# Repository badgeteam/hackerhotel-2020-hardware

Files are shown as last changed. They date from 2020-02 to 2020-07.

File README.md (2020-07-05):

# Hackerhotel 2020 badge
We hope you enjoyed the event!

# Using the design
Should you want to use this design for your own badges then keep in mind that the LED footprints are reversed. Because of this the current design is only suitable for manual assembly! Should you find time to create a version with the LED footprints the right way round (or with the transistors moved to the other side of the LEDs...) then please let us know by creating a pull request.

# License
CERN-OHL-P

Please send in an issue to this repository if you want to use this work under a different license.

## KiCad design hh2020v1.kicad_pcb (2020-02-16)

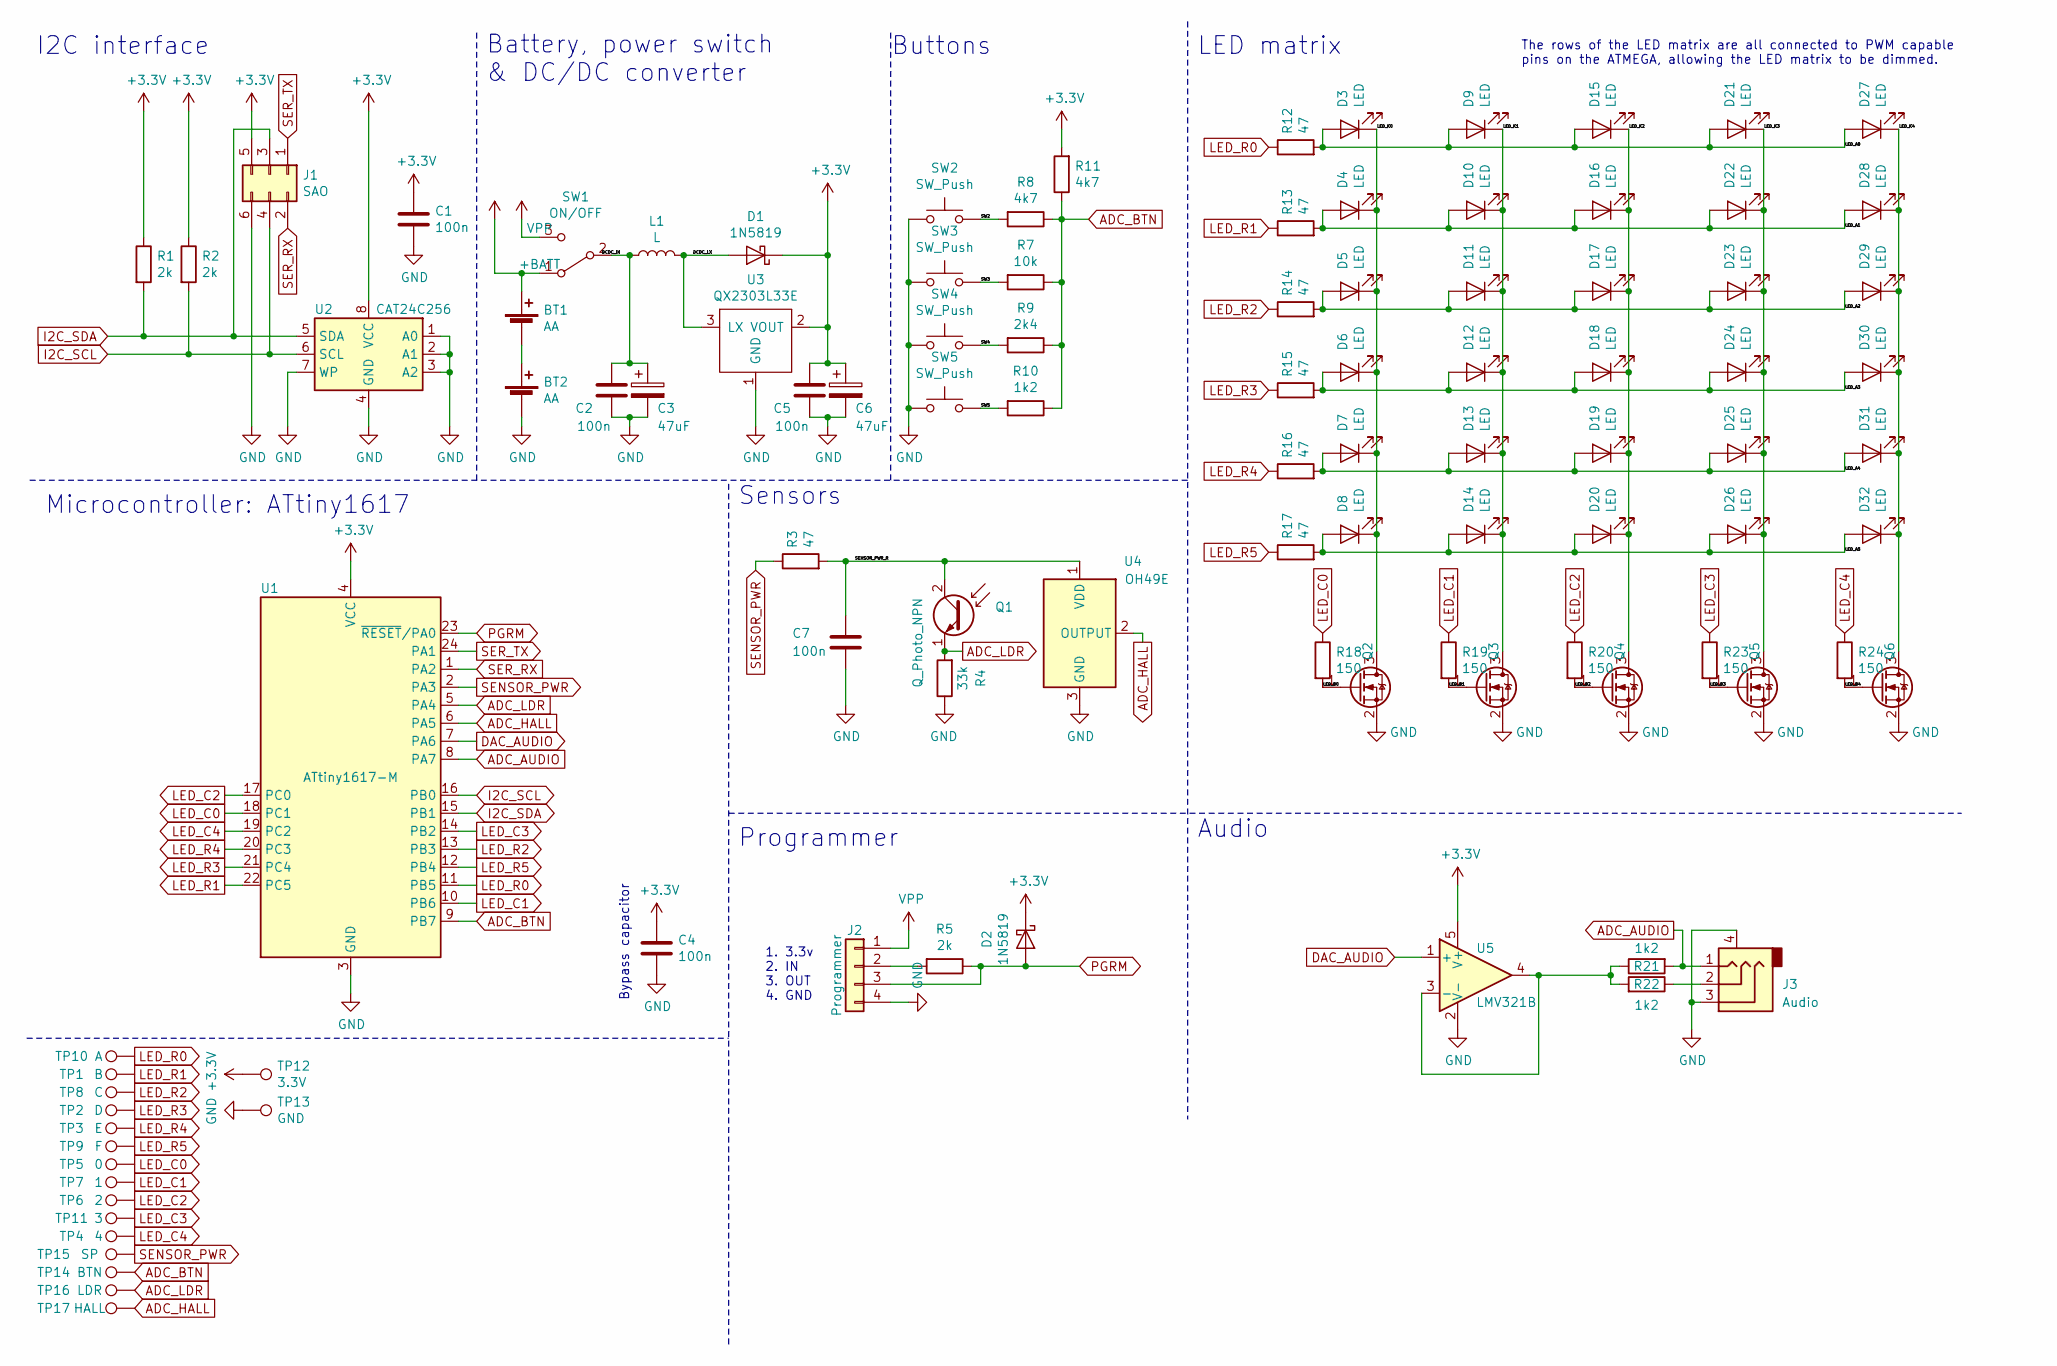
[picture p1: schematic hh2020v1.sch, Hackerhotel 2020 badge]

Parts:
BT1, BT2: AA; BatteryHolder_Keystone_2460_1xAA
C1, C2, C4, C5, C7: 100n; C_0603
C3, C6: 47uF; CP_Tantalum_Case-A_EIA-3216-18_Reflow
D1, D2: 1N5819; D_SOD-123
D3, D4, D5, D6, D7, D8, D9, D10, D11, D12, D13, D14, D15, D16, D17, D18, D19, D20, D21, D22, D23, D24, D25, D26, D27, D28, D29, D30, D31, D32: LED; led-sideways-2.0x0.5
J1: SAO; Pin_Header_Straight_2x03_Pitch2.54mm
J2: Programmer; Pin_Header_Straight_1x04_Pitch2.54mm
J3: Audio; PJ320D_3.5mm_Jack
L1: L; L_Bourns-SRN8040_8x8.15mm
Q1: Q_Photo_NPN; R_0805
Q2, Q3, Q4, Q5, Q6: Q_NMOS_GSD; SOT-23
R1, R2, R5: 2k; R_0603
R3, R12, R13, R14, R15, R16, R17: 47; R_0603
R4: 33k; R_0603
R7: 10k; R_0603
R8, R11: 4k7; R_0603
R9: 2k4; R_0603
R10, R21, R22: 1k2; R_0603
R18, R19, R20, R23, R24: 150; R_0603
SW1: ON/OFF; SW_SPDT_PCM12
SW2, SW3, SW4, SW5: SW_Push; SW_SPST_SKQG
TP1: B; TestPoint_Pad_1.0x1.0mm
TP2: D; TestPoint_Pad_1.0x1.0mm
TP3: E; TestPoint_Pad_1.0x1.0mm
TP4: 4; TestPoint_Pad_1.0x1.0mm
TP5: 0; TestPoint_Pad_1.0x1.0mm
TP6: 2; TestPoint_Pad_1.0x1.0mm
TP7: 1; TestPoint_Pad_1.0x1.0mm
TP8: C; TestPoint_Pad_1.0x1.0mm
TP9: F; TestPoint_Pad_1.0x1.0mm
TP10: A; TestPoint_Pad_1.0x1.0mm
TP11: 3; TestPoint_Pad_1.0x1.0mm
TP12: 3.3V; TestPoint_Pad_1.0x1.0mm
TP13: GND; TestPoint_Pad_1.0x1.0mm
TP14: BTN; TestPoint_Pad_1.0x1.0mm
TP15: SP; TestPoint_Pad_1.0x1.0mm
TP16: LDR; TestPoint_Pad_1.0x1.0mm
TP17: HALL; TestPoint_Pad_1.0x1.0mm
U1: ATtiny1617-M; QFN-24-1EP_4x4mm_P0.5mm_EP2.6x2.6mm
U2: CAT24C256; SOIC-8-N
U3: QX2303L33E; SOT-89-3
U4: OH49E; SOT-23
U5: LMV321B; SOT-23-5

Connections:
+3V3: C1.1, C4.1, C5.2, C6.1, D1.1 (K), D2.1 (K), J1.5, R1.1, R2.1, R11.2, TP12.1, U1.4 (VCC), U2.8 (VCC), U3.2 (VOUT), U5.5 (V+)
+BATT: BT1.1 (+), SW1.1 (A)
/DCDC_IN: C2.2, C3.1, L1.1, SW1.2 (B)
/DCDC_LX: D1.2 (A), L1.2, U3.3 (LX)
/LED_A0: D3.2 (A), D9.2 (A), D15.2 (A), D21.2 (A), D27.2 (A), R12.2
/LED_A1: D4.2 (A), D10.2 (A), D16.2 (A), D22.2 (A), D28.2 (A), R13.2
/LED_A2: D5.2 (A), D11.2 (A), D17.2 (A), D23.2 (A), D29.2 (A), R14.2
/LED_A3: D6.2 (A), D12.2 (A), D18.2 (A), D24.2 (A), D30.2 (A), R15.2
/LED_A4: D7.2 (A), D13.2 (A), D19.2 (A), D25.2 (A), D31.2 (A), R16.2
/LED_A5: D8.2 (A), D14.2 (A), D20.2 (A), D26.2 (A), D32.2 (A), R17.2
/LED_B0: Q2.1 (G), R18.2
/LED_B1: Q3.1 (G), R19.2
/LED_B2: Q4.1 (G), R20.2
/LED_B3: Q5.1 (G), R23.2
/LED_B4: Q6.1 (G), R24.2
/LED_K0: D3.1 (K), D4.1 (K), D5.1 (K), D6.1 (K), D7.1 (K), D8.1 (K), Q2.3 (D)
/LED_K1: D9.1 (K), D10.1 (K), D11.1 (K), D12.1 (K), D13.1 (K), D14.1 (K), Q3.3 (D)
/LED_K2: D15.1 (K), D16.1 (K), D17.1 (K), D18.1 (K), D19.1 (K), D20.1 (K), Q4.3 (D)
/LED_K3: D21.1 (K), D22.1 (K), D23.1 (K), D24.1 (K), D25.1 (K), D26.1 (K), Q5.3 (D)
/LED_K4: D27.1 (K), D28.1 (K), D29.1 (K), D30.1 (K), D31.1 (K), D32.1 (K), Q6.3 (D)
/SENSOR_PWR_R: C7.1, Q1.2 (E), R3.2, U4.1 (VDD)
/SW2: R8.2, SW2.2
/SW3: R7.2, SW3.2
/SW4: R9.2, SW4.2
/SW5: R10.2, SW5.2
ADC_AUDIO: J3.1, R21.2, U1.8 (PA7)
ADC_BTN: R7.1, R8.1, R9.1, R10.1, R11.1, TP14.1, U1.9 (PB7)
ADC_HALL: TP17.1, U1.6 (PA5), U4.2 (OUTPUT)
ADC_LDR: Q1.1 (C), R4.2, TP16.1, U1.5 (PA4)
DAC_AUDIO: U1.7 (PA6), U5.1 (+)
GND: BT2.2 (-), C1.2, C2.1, C3.2, C4.2, C5.1, C6.2, C7.2, J1.6, J2.4, J3.3, J3.4, Q2.2 (S), Q3.2 (S), Q4.2 (S), Q5.2 (S), Q6.2 (S), R4.1, SW2.1, SW3.1, SW4.1, SW5.1, TP13.1, U1.3 (GND), U1.25 (GND), U2.1 (A0), U2.2 (A1), U2.3 (A2), U2.4 (GND), U2.7 (WP), U3.1 (GND), U4.3 (GND), U5.2 (V-)
I2C_SCL: J1.4, R2.2, U1.16 (PB0), U2.6 (SCL)
I2C_SDA: J1.3, R1.2, U1.15 (PB1), U2.5 (SDA)
LED_C0: R18.1, TP5.1, U1.18 (PC1)
LED_C1: R19.1, TP7.1, U1.10 (PB6)
LED_C2: R20.1, TP6.1, U1.17 (PC0)
LED_C3: R23.1, TP11.1, U1.14 (PB2)
LED_C4: R24.1, TP4.1, U1.19 (PC2)
LED_R0: R12.1, TP10.1, U1.11 (PB5)
LED_R1: R13.1, TP1.1, U1.22 (PC5)
LED_R2: R14.1, TP8.1, U1.13 (PB3)
LED_R3: R15.1, TP2.1, U1.21 (PC4)
LED_R4: R16.1, TP3.1, U1.20 (PC3)
LED_R5: R17.1, TP9.1, U1.12 (PB4)
unnamed: BT1.2 (-), BT2.1 (+)
unnamed: J2.2, R5.2
unnamed: J3.2, R22.1
unnamed: R21.1, R22.2, U5.3 (-), U5.4
PGRM: D2.2 (A), J2.3, R5.1, U1.23 (~RESET~/PA0)
SENSOR_PWR: R3.1, TP15.1, U1.2 (PA3)
SER_RX: J1.2, U1.1 (PA2)
SER_TX: J1.1, U1.24 (PA1)
VPP: J2.1, SW1.3 (C)

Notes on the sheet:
LED matrix
Buttons
Microcontroller: ATtiny1617
I2C interface
Bypass capacitor
Battery, power switch & DC/DC converter
Audio
Sensors
The rows of the LED matrix are all connected to PWM capable pins on the ATMEGA, allowing the LED matrix to be dimmed.
1. 3.3v 2. IN 3. OUT 4. GND
Programmer

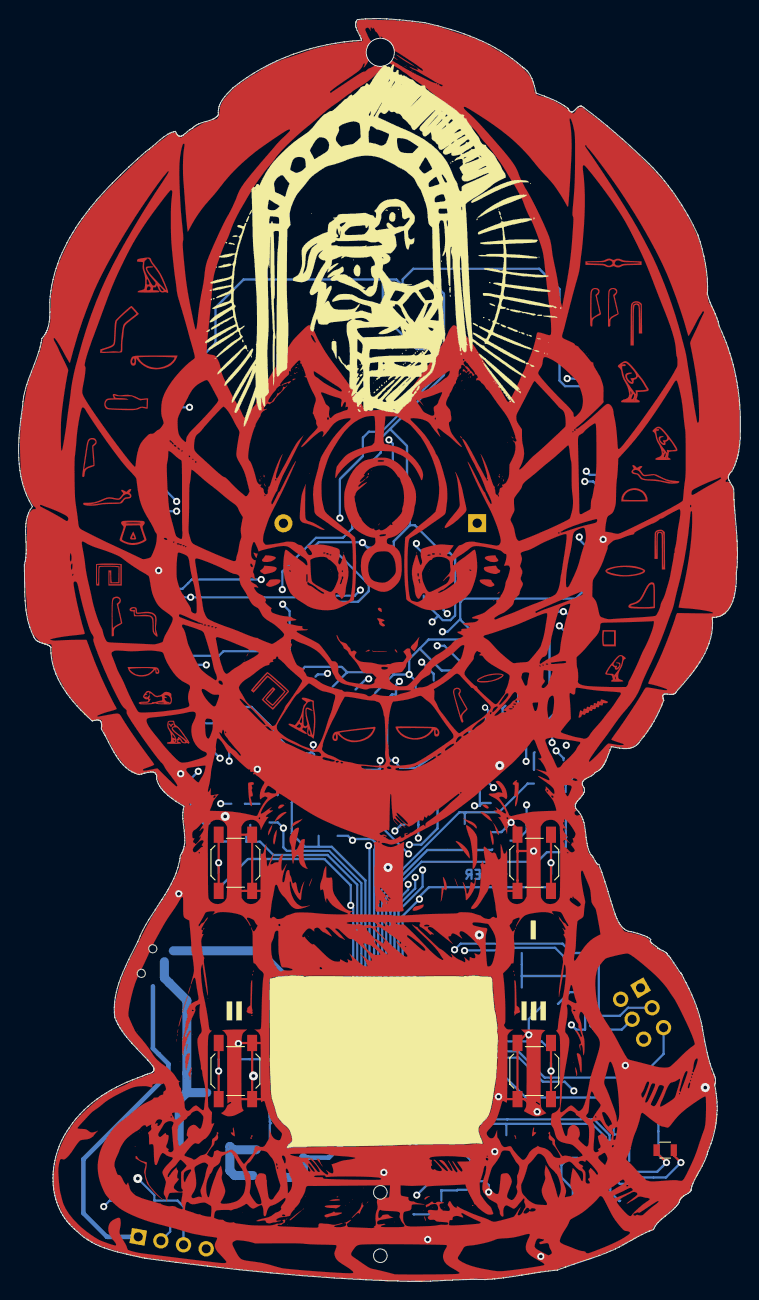
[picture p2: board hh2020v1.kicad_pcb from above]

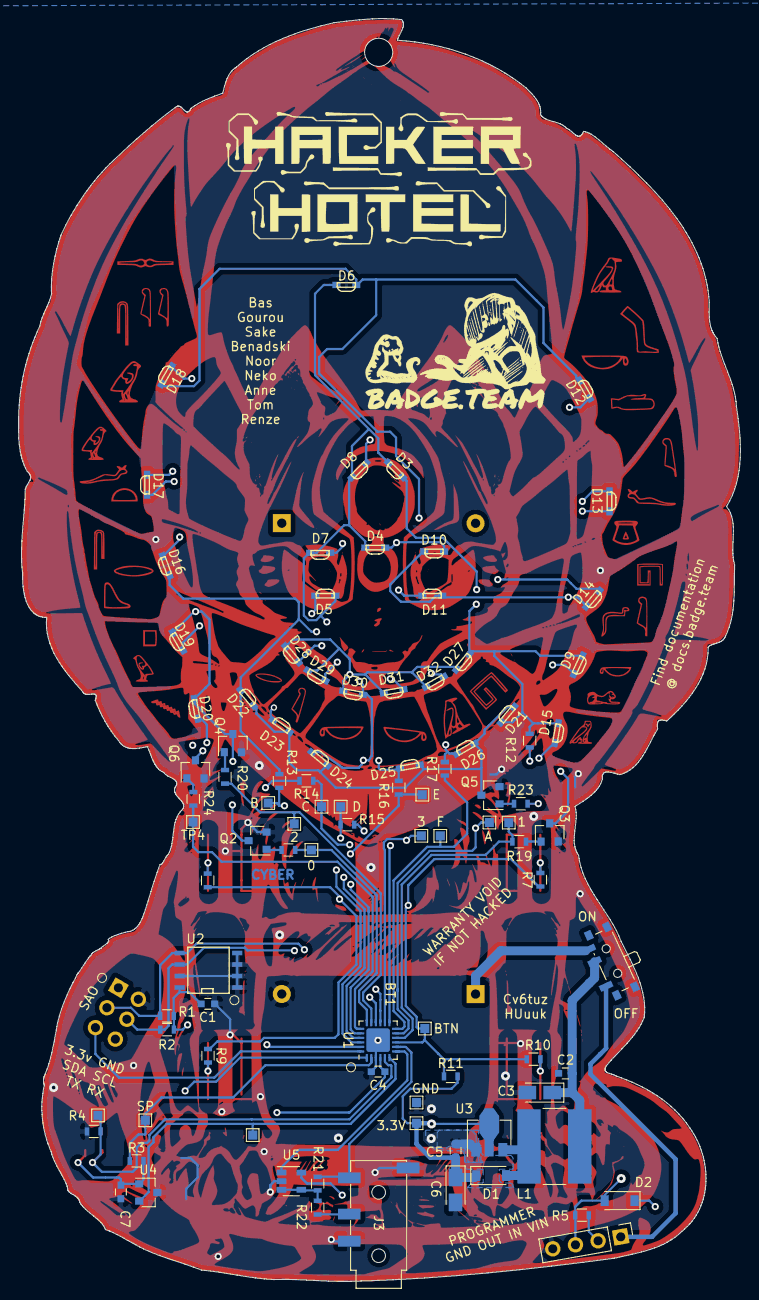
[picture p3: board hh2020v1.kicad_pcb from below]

Board: 4 copper layers, 79.7 x 139.5 mm, 104 parts (95 on the bottom side), 53 nets.

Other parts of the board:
Ref**: Val**; catshape4
Ref**#2: Val**; hackerhotel
Ref**#3: Val**; badgeteam

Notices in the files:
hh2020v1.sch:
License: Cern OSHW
